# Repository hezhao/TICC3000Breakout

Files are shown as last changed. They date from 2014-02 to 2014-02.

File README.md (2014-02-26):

## Summary

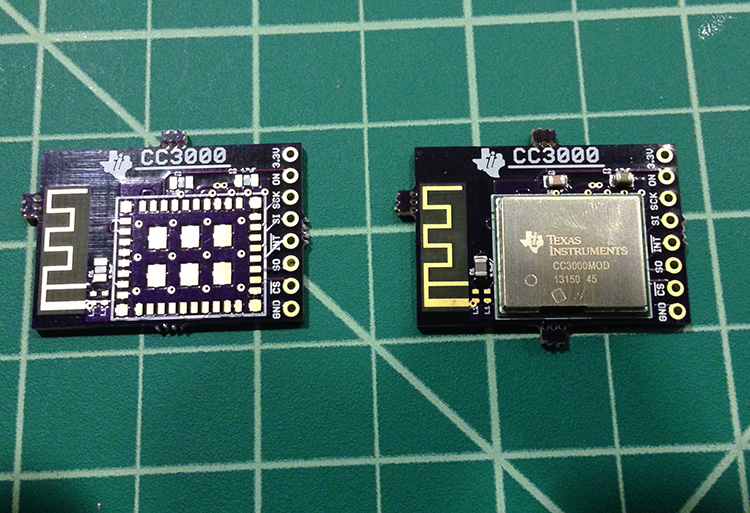
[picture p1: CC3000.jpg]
Photo of CC3000


This is a basic breakout for the TI CC3000 WiFi module based on [Kuy's Design](https://github.com/kuym/TICC3000Breakout), the only difference is that this board uses all 0805 components. 
EAGLE sources.  Open Source / Open Hardware (CC-BY-SA-3.0). You can order the PCB From [OSH Park](http://oshpark.com/shared_projects/wW0yLq3M)

## Parts

	C1: 1pF 0805
	L1, L2: do not populate
	C2: 4.7uF 0805
	C3: 100nF 0805

You may adjust all component values to taste (only C1's value is important.)

## Notes
- Board doesn't pass OSH Park design rule, mainly issues with clearance and stop marks
- Careful with plated ground Vias when soldering components

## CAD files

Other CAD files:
TICC3000WiFiBreakout-tcream.dxf

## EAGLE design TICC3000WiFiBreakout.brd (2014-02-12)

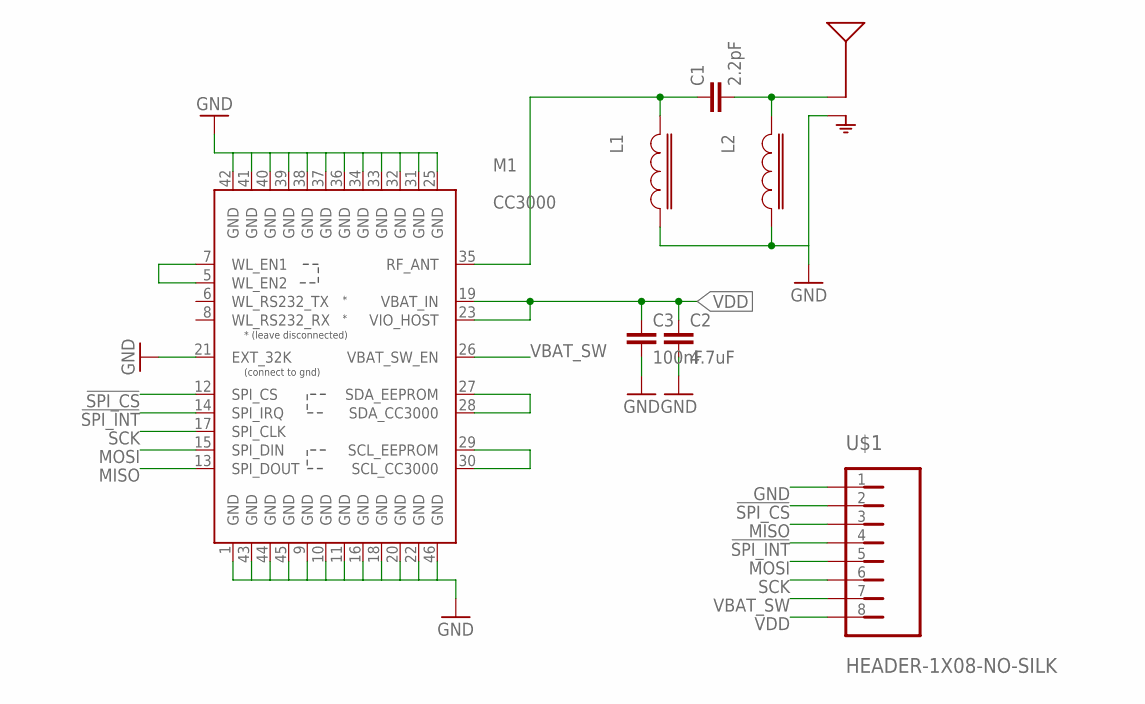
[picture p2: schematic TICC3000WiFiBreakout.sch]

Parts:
ANT1: ANTENNA-TRACE-WITH-GND-2.450GHZ-TI-AN043; ANTENNA-2.450GHZ-TI-AN043
C1: 2.2pF; 0805
C2: 4.7uF; 0805
C3: 100nF; 0805
L1, L2: INDUCTOR-0402-MIN; 0402-MIN
M1: CC3000; TI-CC3000-WIFI-MODULE
U$1: HEADER-1X08-NO-SILK

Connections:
!SPI_CS: M1.12 (SPI_CS), U$1.2
!SPI_INT: M1.14 (SPI_IRQ), U$1.4
GND: ANT1.RFGND (GND), C2.1, C3.1, L1.2, L2.2, M1.1 (GND), M1.9 (GND), M1.10 (GND), M1.11 (GND), M1.16 (GND), M1.18 (GND), M1.20 (GND), M1.21 (EXT_32K), M1.22 (GND), M1.25 (GND), M1.31 (GND), M1.32 (GND), M1.33 (GND), M1.34 (GND), M1.36 (GND), M1.37 (GND), M1.38 (GND), M1.39 (GND), M1.40 (GND), M1.41 (GND), M1.42 (GND), M1.43 (GND), M1.44 (GND), M1.45 (GND), M1.46 (GND), U$1.1
MISO: M1.13 (SPI_DOUT), U$1.3
MOSI: M1.15 (SPI_DIN), U$1.5
unnamed: M1.27 (SDA_EEPROM), M1.28 (SDA_CC3000)
unnamed: M1.29 (SCL_EEPROM), M1.30 (SCL_CC3000)
unnamed: M1.5 (WL_EN2), M1.7 (WL_EN1)
unnamed: C1.2, L1.1, M1.35 (RF_ANT)
unnamed: ANT1.ANT (RF), C1.1, L2.1
SCK: M1.17 (SPI_CLK), U$1.6
VBAT_SW: M1.26 (VBAT_SW_EN), U$1.7
VDD: C2.2, C3.2, M1.19 (VBAT_IN), M1.23 (VIO_HOST), U$1.8

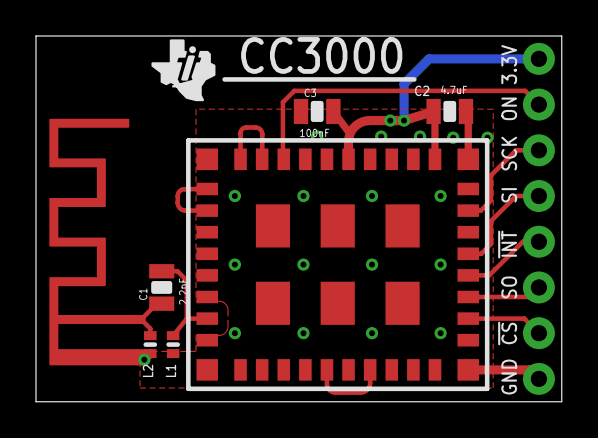
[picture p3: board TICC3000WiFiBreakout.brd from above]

Board: 2 copper layers, 29.2 x 20.3 mm, 8 parts (0 on the bottom side), 13 nets.

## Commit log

2014-02-12 submitted to OSH Park
    [TICC3000WiFiBreakout.brd, TICC3000WiFiBreakout.sch]
2014-02-26 added assembled board pic, added stencil dxf, added silhouette studio project file
    [TICC3000WiFiBreakout-tcream.dxf]
